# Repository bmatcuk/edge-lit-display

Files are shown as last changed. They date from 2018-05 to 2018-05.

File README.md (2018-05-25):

# Edge-lit Display
This repository contains everything you need to build an edge-lit display using
RGB LEDs and laser etched acrylic with a laser cut enclosure.

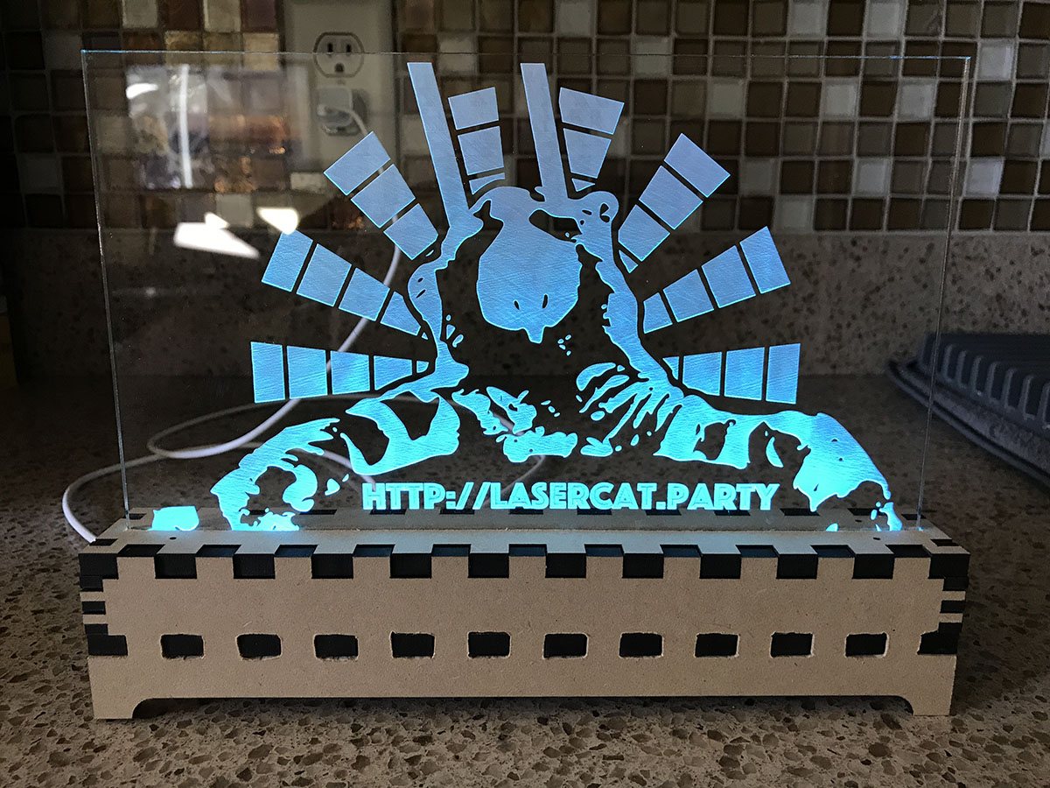
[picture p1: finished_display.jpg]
lasercat party


## System Overview
The display is controlled by an [ATmega32U4], the same microcontroller used in
several [Arduino] boards. It is flashed as an [Arduino Leonardo] over the ICSP
header to make it easier to work with, using an actual [Arduino] as the
programmer. The design surrounding the [ATmega32U4] support circuitry, including
the USB connections, is based on the [Arduino Leonardo] schematics.

The microcontroller communicates with a [TLC5971] over SPI to drive the eight
RGB LEDs. The [TLC5971] is a 12-channel, constant-current sink, 16-bit PWM LED
driver (ie, capable of driving four RGB LEDs at a time). Therefore, the eight
RGB LEDs are divided into two groups and time-multiplexed by the
microcontroller using two high-side PMOS transistors. This allows us to address
each channel of each LED individually.

This circuit is then fitted into a laser cut enclosure with the LEDs directed
into the edge of a laser etched acrylic display. The code on the
microcontroller cycles the colors of the LEDs by rotating through all possible
values for "hue" in the HCY (hue-chroma-luma) colorspace, and converting to 16-
bit RGB for transmission to the [TLC5971].

The whole thing is powered using a standard USB 2.0 cable and includes a
potentiometer to control the brightness of the LEDs by varying the current-
setting resistance of the [TLC5971].

## Schematics
Schematics were designed in [KiCad] v4. This repository has a dependency on my
own [part library] and assumes that my [part library] is located in the same
path as this repository (ie, the `edge-lit display` and `bmatcuk-kicad-library`
directories live in the same directory).

This first schematic is the [ATmega32U4], USB, and support circuitry:

Arduino-Compatible Schematic

The next schematic connects the microcontroller to the LEDs, driver, and high-
side PMOS to time-multiplex the LED groups:

Edge-lit Display

## PCB Layout
The PCB was designed in [KiCad] v4. This repository has a dependency on my
own [part library] and assumes that my [part library] is located in the same
path as this repository (ie, the `edge-lit display` and `bmatcuk-kicad-library`
directories live in the same directory).

The circuit is laid out as a two-layer design. The front layer contains all of
the components and a ground plane with the back layer as a signal layer. This
is probably the weakest part of the whole project as this is the first time
I've laid out a circuit with so many surface mount components in a constrained
space.

Edge-lit Display PCB

## Enclosure
The enclosure was designed in [FreeCAD] 0.17 assuming it would be made out of
MDF wood with a thickness of 0.251in and laser kerf of 0.011in. The screen
was designed for acrylic with a thickness of 3mm and a laser kerf of 0.2mm.
These values can be easily modified in [FreeCAD] by editing the spreadsheet
called "Datum"; the rest of the design will update automatically.

Once the design was complete, 2D projections were made of each piece and these
projections were exported as "flattened svgs". The resulting svg was edited in
[Inkscape] to conform to the format that the manufacturer wanted (ie, to make
the cuts blue, for example).

The svg below might be really difficult to see on your screen because the
stroke width is only 0.01mm. This was a requirement from where I had the
parts laser cut.

Enclosure

## Acrylic Screen
The outline of the screen was designed in [FreeCAD] with the enclosure. Once
the 2D projection was exported as an svg (as mentioned above), it was imported
into [Inkscape] to create the design. Originally, I was going to do some sort
of cityscape, but then I thought it would be more fun to tie this back to a
previous passion project of mine: [lasercat.party] (github: [lasercatparty])!

I edited the photo of the cat in [Photoshop] to remove the background, convert
to greyscale, and then darken some of the light areas with the burn tool, and
lighten some of the dark areas with the dodge tool. The image was then imported
into [Inkscape] and I used the "Trace Bitmap" function to vectorize it. This
was an iterative process: adjusting light and dark areas in [Photoshop], re-
importing in [Inkscape] to vectorize, etc, until I was happy with the result.
The rest of the design was done entirely in [Inkscape]. Then everything was
grouped together and flipped horizontally so that it could be etched on the
back of the acrylic.

The [Photoshop] file is also included in this repository (cat.psd).

Like above, it may be difficult to make out the edge cuts on your screen
because the stroke width is 0.01mm.

Screen

## Manufacturing
The first step was getting the PCB, enclosure, and screen manufactured. I sent
the gerbers to [ALLPCB.com] for PCB manufacturing. I'm very impressed with them
and would definitely recommend. I had the boards in my hands in less than a week
and their prices are very reasonable! The enclosure and screen svgs were sent to
[Ponoko] for laser cutting and etching. Therefore, the MDF and acrylic
thicknesses and kerfs match their specs, and the files are formatted to their
liking (blue for cuts, black for area engraving, red for line engraving; stroke
width of 0.01mm). All electrical components were ordered from [DigiKey]. This
repository includes a Bill Of Material file called `edge-lit display.csv` which
includes all of the [DigiKey] part numbers. You can upload the file to their
website to add all of the parts to your cart.

## Build Log
### Soldering
With PCB and components in hand, the next step is soldering the PCB. We want to
load the [Arduino] bootloader onto our [ATmega32U4], so the first thing we'll
solder is the microcontroller and support circuitry. Installing the [Arduino]
bootloader is done via the ICSP header which uses the SPI pins on the
microcontroller; these pins are also used to control the [TLC5971], so we're
going to leave that and most of the circuitry around it off our board for now.

*Technically*, I think it would be ok to solder everything before installing
the bootloader because it's unlikely that any of the data will make sense to
the [TLC5971] and the microcontroller will tri-state all of the IO pins while
flashing so all of the LEDs will be off anyway, but why risk it? Besides,
pausing to flash the microcontroller mid-solder gives us an opportunity to
make sure everything is working up to that point; troubleshooting will be
easier with fewer components on the board.

That said, I soldered all of the passives (resistors, capacitors, and the
ferrite beads), the varistors, fuse, ICSP header, diode, and [ATmega32U4]. I
technically didn't need to solder all of the passive components, since some of
them are support circuitry for the [TLC5971], but it was easier to solder them
all together. I then tested for any bridged pins with a multimeter, and, when I
was satisfied everything looked good, I moved on to installing the bootloader.

Some tips for soldering: I did most of the soldering with a soldering iron
(my trusty [Hakko FX-888D]) with a beveled tip (the [T18-CF15]). It's possible
to solder everything this way with the liberal application of flux (I have a
[Kester 186 Flux Pen]) - search for "drag soldering" tutorials. I found it
was easier to solder first using this method, and then touch things up a bit
with a hot air rework station (I'm using an [Aoyue Int866]). For example, I
soldered the [ATmega32U4] a little off-center; very hard to fix with an iron,
but short work for the hot air station.

### The Bootloader
To install the bootloader, I flashed an [Arduino Uno] with the ArduinoISP. To
do this in the [Arduino] IDE, select the Uno as the device and open the
ArduinoISP example sketch. Make sure all of the `#define`s are right at the
top of the file and then upload the sketch to the Uno. Next, disconnect the
Uno from your computer and make the following connections:
* 5V on the Uno to pin 2 of the ICSP
* GND on the Uno to pin 6 on the ICSP
* D10 on the Uno (reset signal) to pin 5 on the ICSP
* D11 on the Uno (MOSI) to pin 4 on the ICSP
* D12 on the Uno (MISO) to pin 1 on the ICSP
* D13 on the Uno (SCK) to pin 3 on the ICSP

Other [Arduino]s can be used in place of the [Arduino Uno] using a similar
process. You just need to figure out what pins are used for SPI (MOSI, MISO,
and SCK) and the reset pin. You can actually change the pins in the `#define`s
at the top of the ArduinoISP sketch.

Anyway, once the wired connections are made, reconnect the [Arduino Uno] to
your computer. Select the [Arduino Leonardo] from the device menu, set the port
to where the Uno is connected, change "programmer" to "Arduino as ISP", and
select "Burn Bootloader". This process will take a couple minutes, but it will
test to make sure installation was successful, so if you don't see any errors,
you know your soldering, at least up to this point, is good.

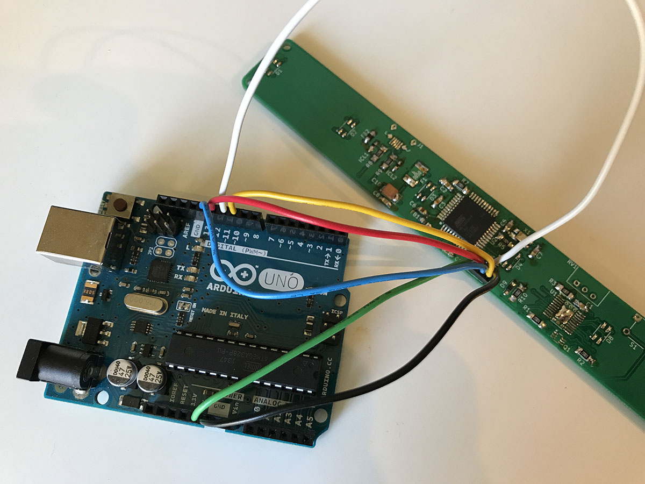
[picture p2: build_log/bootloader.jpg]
Installing the Bootloader


### Soldering Part Deux
After the bootloader is installed, disconnect the [Arduino Uno] and solder
the rest of the components. Now the sketch can be flashed via USB! Connect the
PCB to your computer via USB. If all your soldering went well, you should be
able to flash the code to it by selecting the [Arduino Leonardo] device from the
[Arduino] IDE and uploading. You should hopefully see the LEDs cycle through
all of the colors of the rainbow!

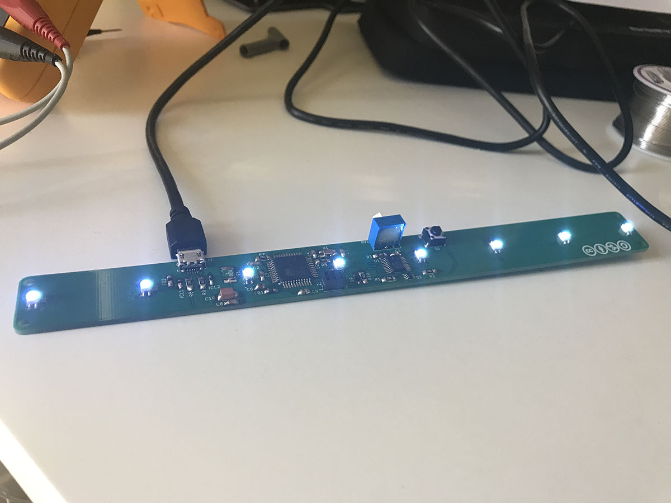
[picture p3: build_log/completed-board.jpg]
Completed Board


### Constructing the Enclosure
Putting the case together is fairly straightforward, but you may find that the
slots are fairly tight. The company I ordered my lasercut parts from ([Ponoko])
didn't have very accurate measurements for wood thickness or kerf. I found the
wood they sent me was around 1.5mm thicker then I was expecting. I had to use a
wood file to make the pieces fit together, and, even then, they were so snug I
didn't bother using any glue.

Basically, you want to put the bottom and sides together, gluing if necessary.
I put the lasercut side (with the burn marks) on the inside to hide it. Then
fit the PCB in. I had planned on using some M2 nylon stand-offs to mount the
PCB (hence the little holes in the top and bottom pieces), but the holes ended
up being too small to thread the stand-offs through. So, instead, I just
hammered some nails through the bottom to keep the PCB from sliding around.

Next, slide the acrylic display through the top piece and put the top of the
enclosure on. The slots on the side pieces should keep the acrylic from falling
over, and should line it up to be right on top of the LEDs. If you are
sucessfully using stand-offs, you can have some stand-offs go to the top of the
enclosure, too.

I adjusted some of the calculations in the [FreeCAD] model after I received my
lasercut enclosure to hopefully make it less snug. I also regenerated the
enclosure.svg file, but I haven't tried getting another enclosure made up.

## License
Software in this repository is licensed under the [MIT] license. Hardware
schematics are released under a Creative Commons Attribution and Share Alike
license ([CC-BY-SA] 4.0). PCB layout designs, enclosure designs, and acrylic
display designs are licensed under a Creative Commons Attribution, Non-
Commercial, Share Alike license ([CC-BY-NC-SA] 4.0).

[ALLPCB.com]: http://www.allpcb.com/
[ATmega32U4]: http://www.microchip.com/wwwproducts/en/ATmega32u4
[Aoyue Int866]: https://www.aoyue.eu/aoyue-int866-3in1-rework-station-lead-free-hot-air-soldering-station.html
[Arduino Leonardo]: https://store.arduino.cc/usa/arduino-leonardo-with-headers
[Arduino Uno]: https://store.arduino.cc/usa/arduino-uno-rev3
[Arduino]: https://www.arduino.cc/
[CC-BY-NC-SA]: https://creativecommons.org/licenses/by-nc-sa/4.0/
[CC-BY-SA]: https://creativecommons.org/licenses/by-sa/4.0/
[DigiKey]: https://www.digikey.com/
[FreeCAD]: https://www.freecadweb.org/
[Hakko FX-888D]: https://www.hakkousa.com/products/soldering/hakko-fx-888d-digital-soldering-station-10145.html
[Inkscape]: https://inkscape.org/
[Kester 186 Flux Pen]: https://www.kester.com/products/product/186-flux-pen
[KiCad]: http://kicad-pcb.org/
[MIT]: https://choosealicense.com/licenses/mit/
[Photoshop]: https://www.adobe.com/products/photoshop.html
[Ponoko]: https://www.ponoko.com/
[T18-CF15]: https://www.hakkousa.com/products/soldering-iron-tips/t18-series/t18-cf15.html
[TLC5971]: http://www.ti.com/product/TLC5971
[lasercat.party]: http://lasercat.party
[lasercatparty]: https://github.com/bmatcuk/lasercatparty
[part library]: https://github.com/bmatcuk/bmatcuk-kicad-library/

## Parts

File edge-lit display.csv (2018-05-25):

Item | Qty | Reference(s) | Value | LibPart | Footprint | Datasheet | Description | Manufacturer | Manufacturer Part | Supplier | Supplier Part
1 | 5 | C1, C2, C3, C4, C8 | 100nF | part-library:C | part-library:0805 | http://www.samsungsem.com/kr/support/product-search/mlcc/__icsFiles/afieldfile/2016/08/18/S_CL21B104KOANNNC.pdf | CAP CER 0.1UF 16V X7R 0805 | Samsung Electro-Mechanics | CL21B104KOANNNC | DigiKey | 1276-2448-1-ND
2 | 2 | C5, C7 | 12pF | part-library:C | part-library:0805 | http://www.samsungsem.com/kr/support/product-search/mlcc/__icsFiles/afieldfile/2016/08/18/S_CL21C120JBANNNC.pdf | CAP CER 12PF 50V C0G/NP0 0805 | Samsung Electro-Mechanics | CL21C120JBANNNC | DigiKey | 1276-1120-1-ND
3 | 2 | C6, C9 | 1uF | part-library:C | part-library:0805 | http://www.samsungsem.com/kr/support/product-search/mlcc/__icsFiles/afieldfile/2016/08/18/S_CL21B105KOFNNNG.pdf | CAP CER 1UF 16V X7R 0805 | Samsung Electro-Mechanics | CL21B105KOFNNNG | DigiKey | 1276-6471-1-ND
4 | 1 | C10 | 10uF | part-library:CP | part-library:1210 | http://datasheets.avx.com/TAJ_AUTO.pdf | CAP TANT 10UF 10% 10V 1210 | AVX Corporation | TAJB106K010TNJ | DigiKey | 478-11224-1-ND
5 | 8 | D1, D2, D3, D4, D5, D6, D7, D8 | LED_ARGB | part-library:LED_ARGB | part-library:PLCC4 | http://www.cree.com/led-components/media/documents/CLV1L-FKB-1238.pdf | LED RGB 4PLCC SMD | Cree Inc. | CLV1L-FKB-CJMNQEGBB7673673 | DigiKey | CLV1L-FKB-CJMNQEGBB7673673CT-ND
6 | 1 | D9 | 1N4148WS | part-library:1N4148WS | part-library:SOD-323FL | http://www.taiwansemi.com/products/datasheet/1N4148WS%20SERIES_K1709.pdf | DIODE GEN PURP 75V 150MA SOD323F | Taiwan Semiconductor Corporation | 1N4148WS RRG | DigiKey | 1N4148WSRRGCT-ND
7 | 1 | F1 | Fuse-500mA | part-library:Fuse-500mA | part-library:1812_Concave | https://www.belfuse.com/resources/CircuitProtection/datasheets/0ZCG%20Nov2016.pdf | PTC RESET FUSE 16V 500MA 1812 | Bel Fuse Inc. | 0ZCG0050FF2C | DigiKey | 507-1761-1-ND
8 | 2 | FB1, FB2 | Ferrite_Bead_30Ohm | part-library:Ferrite_Bead_30Ohm | part-library:0805 | http://www.bourns.com/docs/Product-Datasheets/mh.pdf | FERRITE BEAD 30 OHM 0805 1LN | Bourns Inc. | MH2029-300Y | DigiKey | MH2029-300YCT-ND
9 | 2 | ICL1, ICL2 | Varistor | part-library:Varistor | part-library:0603 | http://www.bourns.com/docs/Product-Datasheets/MLC.pdf | VARISTOR 0603 | Bourns Inc. | CG0603MLC-05E | DigiKey | CG0603MLC-05ECT-ND
10 | 1 | J1 | USB-Micro-B | part-library:USB-Micro-B | part-library:USB_Micro_B_Female | http://cdn.amphenol-icc.com/media/wysiwyg/files/drawing/10118194.pdf | CONN USB MICRO B RECPT SMT R/A | Amphenol FCI | 10118194-0001LF | DigiKey | 609-4618-1-ND
11 | 1 | J2 | CONN_03X2FEMALE | part-library:CONN_03X2FEMALE | part-library:2X3 | http://www.te.com/commerce/DocumentDelivery/DDEController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 | CONN RCPT 6POS VERT 2MM T/H | TE Connectivity AMP Connectors | 2-1734506-6 | DigiKey | A115093-ND
12 | 1 | Q1 | Dual-PMOS | part-library:Dual-PMOS | part-library:SOT-363 | http://www.comchiptech.com/cms/UserFiles/CJ3139KDW-G%20RevA829375.pdf | MOSFET 2PCH 20V 660MA SOT363 | Comchip Technology | CJ3139KDW-G | DigiKey | 641-1793-1-ND
13 | 4 | R1, R2, R7, R10 | 10k | part-library:R | part-library:1206 | http://www.yageo.com/documents/recent/PYu-RC_Group_51_RoHS_L_9.pdf | RES SMD 10K OHM 1% 1/4W 1206 | Yageo | RC1206FR-0710KL | DigiKey | 311-10.0KFRCT-ND
14 | 1 | R3 | 3.3k | part-library:R | part-library:1206 | http://www.yageo.com/documents/recent/PYu-RC_Group_51_RoHS_L_9.pdf | RES SMD 3.3K OHM 1% 1/4W 1206 | Yageo | RC1206FR-073K3L | DigiKey | 311-3.30KFRCT-ND
15 | 2 | R4, R6 | 0 | part-library:R | part-library:SolderJumper-NC |  |  |  |  | DigiKey
16 | 1 | R5 | 1M | part-library:R | part-library:1206 | http://www.yageo.com/documents/recent/PYu-RC_Group_51_RoHS_L_9.pdf | RES SMD 1M OHM 1% 1/4W 1206 | Yageo | RC1206FR-071ML | DigiKey | 311-1.00MFRCT-ND
17 | 2 | R8, R9 | 22 | part-library:R | part-library:1206 | http://www.yageo.com/documents/recent/PYu-RC_Group_51_RoHS_L_9.pdf | RES SMD 22 OHM 1% 1/4W 1206 | Yageo | RC1206FR-0722RL | DigiKey | 311-22.0FRCT-ND
18 | 1 | RV1 | 10k | part-library:POT | part-library:Bourns_3310C | http://www.bourns.com/docs/Product-Datasheets/3310.pdf | POT 10K OHM 1/4W PLASTIC LINEAR | Bourns Inc. | 3310C-125-103L | DigiKey | 3310C-125-103L-ND
19 | 1 | S1 | SPST-NO | part-library:SPST-NO | part-library:SPST_6mm | http://www.te.com/commerce/DocumentDelivery/DDEController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 | SWITCH TACTILE SPST-NO 0.05A 24V | TE Connectivity ALCOSWITCH Switches | 1825910-6 | DigiKey | 450-1650-ND
20 | 1 | U1 | TLC59711PWPR | part-library:TLC59711PWPR | part-library:HTSSOP-20 | http://www.ti.com/lit/ds/symlink/tlc5971.pdf | IC LED DRIVER LIN 60MA 20HTSSOP | Texas Instruments | TLC5971PWPR | DigiKey | 296-27796-1-ND
21 | 1 | U2 | ATMEGA32U4TQFP-44 | part-library:ATMEGA32U4TQFP-44 | part-library:TQFP44 | http://ww1.microchip.com/downloads/en/DeviceDoc/Atmel-7766-8-bit-AVR-ATmega16U4-32U4_Datasheet.pdf | IC MCU 8BIT 32KB FLASH 44TQFP | Microchip Technology | ATMEGA32U4-AU | DigiKey | ATMEGA32U4-AU-ND
22 | 1 | X1 | 16MHZ | part-library:16MHZ | part-library:4SMD | http://www.txccorp.com/download/products/quartz_crystals/2015TXC_7M_17.pdf | CRYSTAL 16.0000MHZ 12PF SMD | TXC CORPORATION | 7M-16.000MAAE-T | DigiKey | 887-1904-1-ND

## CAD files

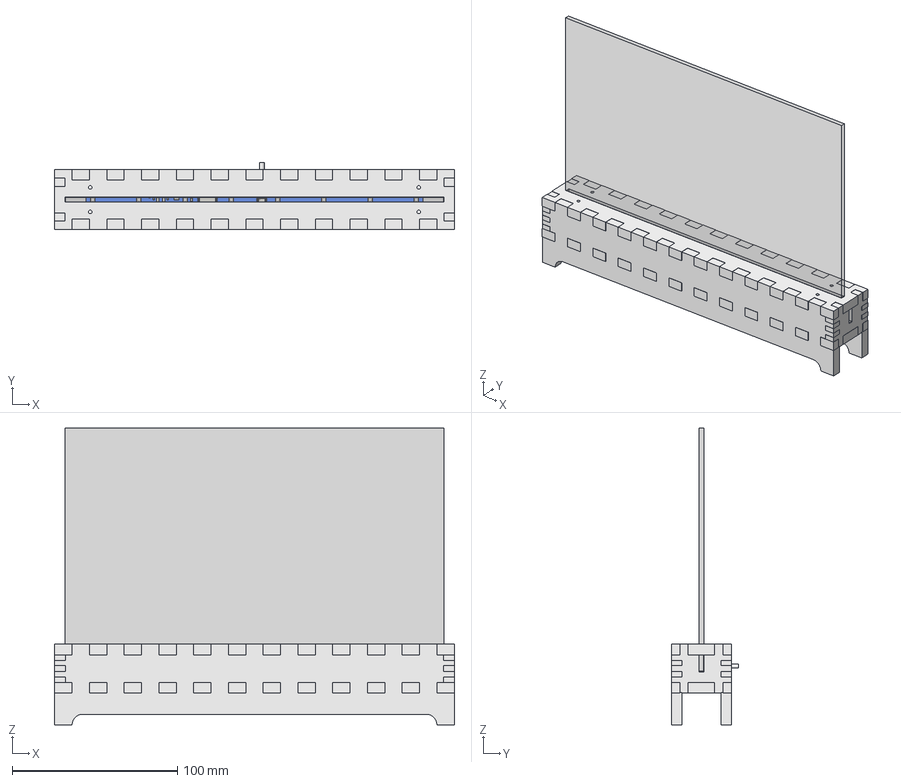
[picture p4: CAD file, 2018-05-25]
edge_lit_display.FCStd
242.2 x 40.8 x 179.6 mm
Pcb
C_0805_
C_0805_001
C_0805_002
C_0805_003
C_0805_004
C_0805_005
C_0805_006
C_0805_007
C_0805_008
C_1210_
Cree_3d2mm_RGB
Cree-3.2mm-RGB_001
Cree-3.2mm-RGB_002
Cree-3.2mm-RGB_003
Cree-3.2mm-RGB_004
Cree-3.2mm-RGB_005
Cree-3.2mm-RGB_006
Cree-3.2mm-RGB_007
D_SOD_323F_
R_1812_
L_0805_
L_0805_001
R_0603_
R_0603_001
USB
SOT_363_SC_70_6_
R_1206_
R_1206_001
R_1206_002
R_1206_003
R_1206_004
R_1206_005
R_1206_006
R_1206_007
Dimmer
HTSSOP_20_1EP_44x65mm_Pitch065mm_ThermalPad_
TQFP-44_10x10mm_Pitch0.8mm_

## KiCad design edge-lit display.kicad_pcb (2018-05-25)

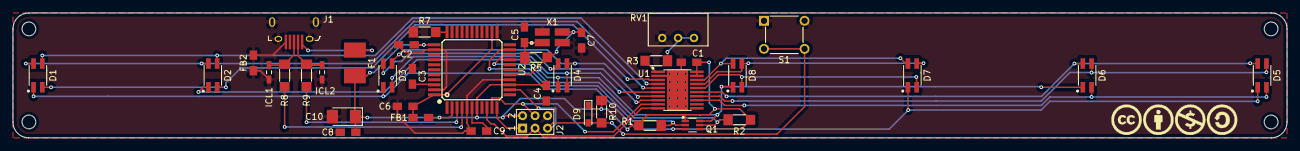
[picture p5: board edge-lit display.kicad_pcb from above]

Board: 2 copper layers, 204.0 x 20.0 mm, 40 parts (0 on the bottom side), 35 nets.

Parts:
C1, C2, C3, C4, C8: 100nF; 0805
C5, C7: 12pF; 0805
C6, C9: 1uF; 0805
C10: 10uF; 1210
D1, D2, D3, D4, D5, D6, D7, D8: LED_ARGB; PLCC4
D9: 1N4148WS; SOD-323FL
F1: Fuse-500mA; 1812_Concave
FB1, FB2: Ferrite_Bead_30Ohm; 0805
ICL1, ICL2: Varistor; 0603
J1: USB-Micro-B; USB_Micro_B_Female
J2: CONN_03X2FEMALE; 2X3
Q1: Dual-PMOS; SOT-363
R1, R2, R7, R10: 10k; 1206
R3: 3.3k; 1206
R5: 1M; 1206
R8, R9: 22; 1206
RV1: 10k; Bourns_3310C
S1: SPST-NO; SPST_6mm
U1: TLC59711PWPR; HTSSOP-20
U2: ATMEGA32U4TQFP-44; TQFP44
X1: 16MHZ; 4SMD

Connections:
+5V: C1.1, C2.1, C4.1, C8.1, C10.1, D9.1, F1.1, FB1.1, J2.2, Q1.1, Q1.4, R1.1, R2.1, R10.2, U1.19, U1.20, U2.2, U2.7, U2.14, U2.34
/Arduino Compatible/AREF: C3.1, U2.42
/Arduino Compatible/AVCC: C6.1, FB1.2, U2.24, U2.44
/Arduino Compatible/D0: Q1.5, R2.2, U2.20
/Arduino Compatible/D1: Q1.2, R1.2, U2.21
/Arduino Compatible/D14/MISO: J2.1, U2.11
/Arduino Compatible/D15/SCK: J2.3, U1.10, U2.9
/Arduino Compatible/D16/MOSI: J2.4, U1.9, U2.10
/Arduino Compatible/D+: R8.1, U2.4
/Arduino Compatible/D-: R9.1, U2.3
/Arduino Compatible/RESET: D9.2, J2.5, R10.1, S1.3, S1.4, U2.13
/Arduino Compatible/XTAL1: C5.1, R5.2, U2.17, X1.1
/Arduino Compatible/XTAL2: C7.1, R5.1, U2.16, X1.3
GNDA: C1.2, C2.2, C3.2, C4.2, C5.2, C6.2, C7.2, C8.2, C9.2, C10.2, FB2.1, FB2.2, ICL1.2, ICL2.2, J1.5, J1.6, J2.6, R7.2, RV1.3, S1.1, S1.2, U1.2, U1.21, U2.5, U2.15, U2.23, U2.35, U2.43, X1.2, X1.4
unnamed: C9.1, U2.6
unnamed: D1.1, D3.1, D5.1, D7.1, Q1.3
unnamed: D1.2, D2.2, U1.3
unnamed: D1.3, D2.3, U1.4
unnamed: D1.4, D2.4, U1.5
unnamed: D2.1, D4.1, D6.1, D8.1, Q1.6
unnamed: D3.2, D4.2, U1.6
unnamed: D3.3, D4.3, U1.7
unnamed: D3.4, D4.4, U1.8
unnamed: D5.2, D6.2, U1.13
unnamed: D5.3, D6.3, U1.14
unnamed: D5.4, D6.4, U1.15
unnamed: D7.2, D8.2, U1.16
unnamed: D7.3, D8.3, U1.17
unnamed: D7.4, D8.4, U1.18
unnamed: F1.2, J1.1
unnamed: ICL1.1, J1.3, R8.2
unnamed: ICL2.1, J1.2, R9.2
unnamed: R3.1, U1.1
unnamed: R3.2, RV1.1, RV1.2
unnamed: R7.1, U2.33

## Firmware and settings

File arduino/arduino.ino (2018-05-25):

/**
 * Edge-lit Display
 * Bob Matcuk
 * https://github.com/bmatcuk/edge-lit-display
 * 
 * This code is released under the MIT license.
 */
#include <SPI.h>

// If uncommented, the computed RGB values
// will be streamed into the serial monitor.
// #define DEBUG

const SPISettings SPI_SETTINGS = SPISettings(20000000, MSBFIRST, SPI_MODE0);
#define DELAY 1

#define MAX_UINT16   0xffff
#define HCY_R_WEIGHT 19661  // .3
#define HCY_G_WEIGHT 38666  // .59
#define HCY_B_WEIGHT  7209  // .11

uint16_t HUE = 0;
const uint16_t CHROMA = 0xffff;
const uint16_t LUMA = 0x7fff;
uint8_t GROUP = 0;

/**
 * Divides hue into six "even" buckets (16 bits doesn't evenly divide into 6)
 * and returns which bucket the hue falls into as hprime. The xfactor is
 *   for odd buckets:
 *     hue - max value of the previous bucket
 *   for even buckets:
 *     max of this bucket - hue
 */
void hprime_and_xfactor(const uint16_t hue, uint8_t *hprime, int32_t *xfactor) {
  if (hue < 10922) {
    *hprime = 0;
    *xfactor = hue;
  } else if (hue < 21845) {
    *hprime = 1;
    *xfactor = 21845 - hue;
  } else if (hue < 32767) {
    *hprime = 2;
    *xfactor = hue - 21845;
  } else if (hue < 43690) {
    *hprime = 3;
    *xfactor = 43690 - hue;
  } else if (hue < 54612) {
    *hprime = 4;
    *xfactor = hue - 43690;
  } else {
    *hprime = 5;
    *xfactor = MAX_UINT16 - hue;
  }
}

// https://en.wikipedia.org/wiki/HSL_and_HSV#From_luma.2Fchroma.2Fhue
void hcy_to_rgb(
    const uint16_t hue, const uint16_t chroma, const uint16_t luma,
    uint16_t *r, uint16_t *g, uint16_t *b) {
  uint8_t hprime;
  int32_t x;
  hprime_and_xfactor(hue, &hprime, &x);
  x = (int32_t)chroma * x / 10922; // 55544

  int32_t r32 = 0, g32 = 0, b32 = 0;
  switch (hprime) {
    case 0:
      r32 = chroma;
      g32 = x;
      break;
    case 1:
      r32 = x;
      g32 = chroma;
      break;
    case 2:
      g32 = chroma;
      b32 = x;
      break;
    case 3:
      g32 = x;
      b32 = chroma;
      break;
    case 4:
      r32 = x;
      b32 = chroma;
      break;
    case 5:
      r32 = chroma;
      b32 = x;
      break;
  }

  // 32767 - 19661 - 38666 * 55544 / 65535
  int32_t m = (int32_t)luma - (int32_t)(
    (uint32_t)r32 * HCY_R_WEIGHT / MAX_UINT16
    + (uint32_t)g32 * HCY_G_WEIGHT / MAX_UINT16
    + (uint32_t)b32 * HCY_B_WEIGHT / MAX_UINT16);
  r32 += m;
  g32 += m;
  b32 += m;

  *r = (uint16_t)constrain(r32, 0, MAX_UINT16);
  *g = (uint16_t)constrain(g32, 0, MAX_UINT16);
  *b = (uint16_t)constrain(b32, 0, MAX_UINT16);
}

void setup() {
  // Arduino pin "0" corresponds to pin 20 on the ATmega32U4 (aka D0)
  // Arduino pin "1" corresponds to pin 21 on the ATmega32U4 (aka D1)
  pinMode(0, OUTPUT);
  pinMode(1, OUTPUT);
  digitalWrite(0, LOW);
  digitalWrite(1, HIGH);
  SPI.begin();
}

void loop() {
  // Get our RGB values
  uint16_t r, g, b;
  hcy_to_rgb(HUE, CHROMA, LUMA, &r, &g, &b);

  #ifdef DEBUG
  // Send the values to the serial monitor
  Serial.print(HUE, HEX);
  Serial.print('=');
  Serial.print(r, HEX);
  Serial.print(',');
  Serial.print(g, HEX);
  Serial.print(',');
  Serial.println(b, HEX);
  #endif

  // Begin sending the updated information to the TLC5971
  SPI.beginTransaction(SPI_SETTINGS);

  // Write command, ~out timing, ~external clock
  SPI.transfer(0b10010100);

  // Timing reset, repeat mode, ~blank, and first 5 bits of BC for blue
  SPI.transfer(0b11011000);

  // 2 remaining LSB of BC for blue, plus first 6 bits of BC for green
  SPI.transfer(0b00110000);

  // remaining LSB of BC for green, plus all 7 bits of BC for red
  SPI.transfer(0b01111111);
  
  for (uint8_t i = 0; i < 4; i++) {
    SPI.transfer16(b);
    SPI.transfer16(g);
    SPI.transfer16(r);
  }

  // Finished sending to the TLC5971
  SPI.endTransaction();

  // LEDs are divided into two "groups" and time-multiplexed.
  // Swap which group we'll light on the next pass...
  if (GROUP == 0) {
    digitalWrite(1, LOW);
    digitalWrite(0, HIGH);
  } else {
    digitalWrite(0, LOW);
    digitalWrite(1, HIGH);

    // After lighting both groups, increment the HUE
    HUE++;
  }
  GROUP ^= 1;
}
